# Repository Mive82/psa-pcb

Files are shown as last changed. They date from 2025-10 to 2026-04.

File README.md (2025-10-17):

# Important

**NOTE:** Unless you have access to a bunch of weird ICs used here, a way to solder 0201 and 0402 components,
and willpower to fix the defects listed below, don't bother assemblying the v1.0 version of the PCB.

# Peugeot Infotainment Project PCB

This is a repository for the PCB used in the second revision of the Peugeot Infotainment Project.
For the first revision, see the v0.1 branch.

It used <https://github.com/morcibacsi/PSAVanCanBridgeHW> as a base for the VAN communication hardware.

For more information, check out <https://github.com/Mive82/psa-docs>

## About the board

Unlike the previous v0.1 revision, on the v1.0 revision everything is contained on the board:
- Dual buck converter chips: One for the ESP and other ICs on the board (Battery power) and one for the Raspberry Pi and display (VAN+).
  - 3.3V LDO for the ESP32 after the 5V buck converter. Allows for very low voltage on the 12V input down to about 4 volts and the ESP will still work.
- ESP32-WROOM module. The USB to UART converter is not inclued, but the extra pins for resetting and flashing the board are routed to the connector.
- TSS463C VAN driver. Connected with a level shifter to the ESP
- MCP2551 CAN transciever. The RX pin is also connected to the ESP to allow receving in software.
- DS3231 RTC Chip for keeping the time. Connected to the Pi.

## Connections

The board has three JST GH connectors:
- Car power and data (JST GH 6 pin)
  - 12V battery power
  - 12V Switched (+VAN) power
  - VAN DATA and DATAB lines
- Display power output (JST GH 4 pin)
  - Outputs 5V for an external display
  - Also routes I2C pins from the Pi if needed
- ESP programming (JST GH 6 pin)
  - UART TX, RX, RTS and DTR pins as well as GND.

# Board Defects

Being the first proper revision, there are a lot of defects. Luckily they can all be solved.

## ESP flashing issues

The `GPIO12` pin is used for SPI communication with the TSS463C. It is also used as a strapping pin for determining the voltage used
to access the onboard flash. This pin is floating, so the value will not always be correct. This will result in regular booting
and flashing issues.

**SOLUTION**: Burn eFuses with `esptool.py` to permanently set the voltage used. On the ESP32-WROOM module we used, the voltage was 3.3V [Implemented]

## ESP first boot issues

When first powering the board on, the ESP will always boot into flash mode. This is because of a capacitor on the `GPIO0` pin that was not needed: `C6`.

**SOLUTION**: Remove the `C6` capacitor. [Implemented]

## VAN TX not working

The transistor switches used for putting the MCP2551 in a low-power state and resetting the TSS are not designed correctly.
They don't reset the TSS, but the MCP2551 is always put in a low power state which prevents it from sending any CAN/VAN data.

**SOLUTION**: Remove both transistor switches and surrounding hardware (`Q6`, `R21`, `R1`, `Q5` and `C1`). [Implemented]
Pull pin `Rs` on the MCP2551 to GND with a 4.7k resistor. Note that, according the datasheet, this will increase power draw
by 9 or 10 mA. [Implemented]

## ESP32 VAN RX not working after VAN+ dissapears

This issue occured due to an oversight on level shifter pins. The VCC reference pin on one side is tied to the VAN+ regulator and will
dissapear when VAN+ dissapears.

**SOLUTION**: On chip U11 cut the trace connecting pin 11 (`VCC(B)`) and `+5V ignition`. then connect pin 11 to `+5V Car Battery`. [Implemented]
Best location would the one of the pads of `R21` which is be removed to fix the issue above this one. 

### High deep sleep power consumption

The board pulls about 35mA on 12V during deep sleep. This increases the more voltage increases.
Not yet sure what is causing this, but removing the pull resistors from the `MODE` pins on the buck regulators reduces it to about 12mA.

**PARTIAL SOLUTION**: Remove `R110` and `R118`. [Implemented]

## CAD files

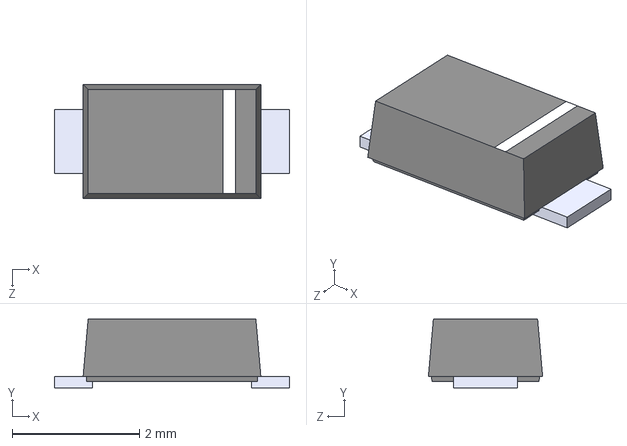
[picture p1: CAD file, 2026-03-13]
3dModels/VTVS11ASMF-M3-08.STEP
3.70 x 1.08 x 1.80 mm

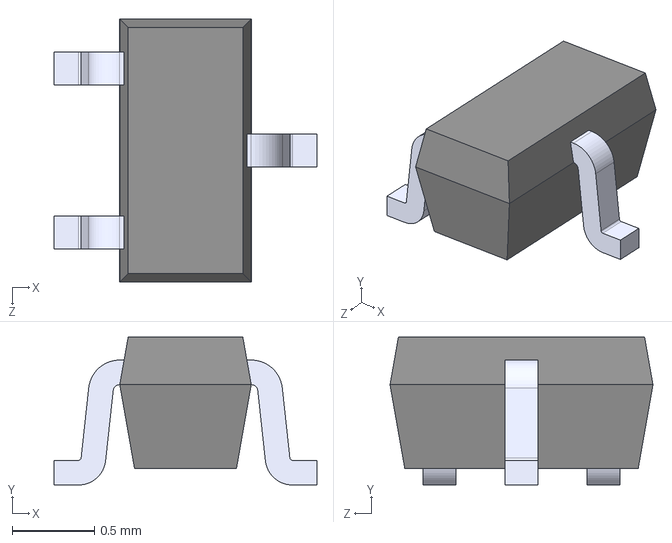
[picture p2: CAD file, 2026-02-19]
3dModels/npn.STEP
1.60 x 0.9 x 1.60 mm

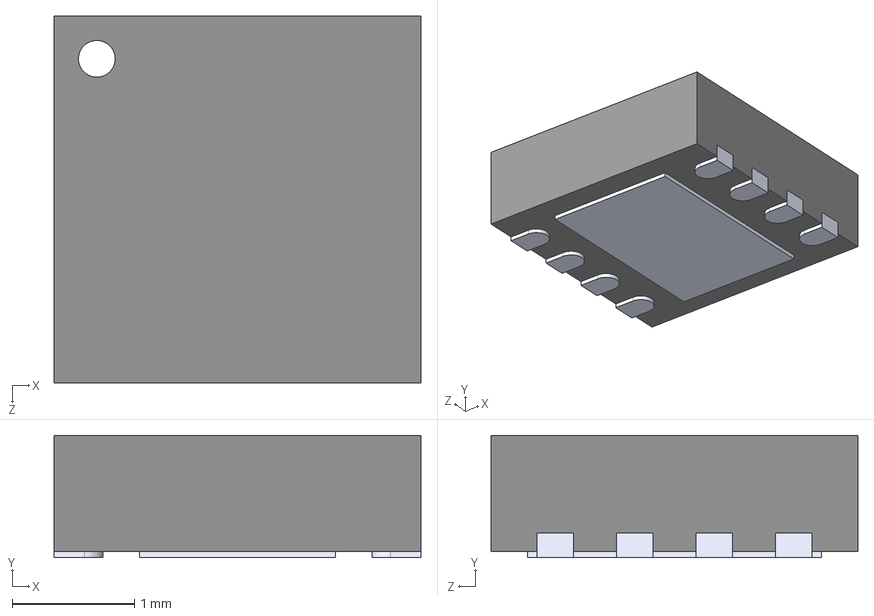
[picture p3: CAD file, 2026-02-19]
3dModels/TJA1051TK_3_1J.STEP
3.00 x 1.00 x 3.00 mm

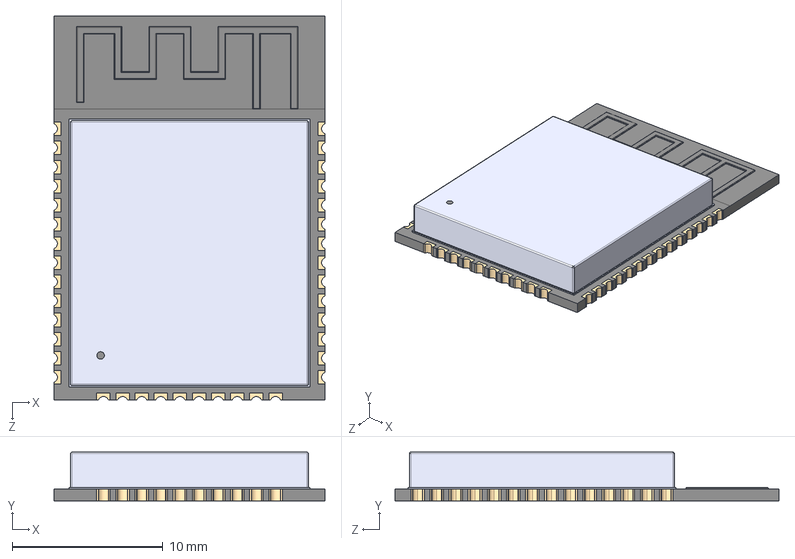
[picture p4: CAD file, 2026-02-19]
3dModels/ESP32-WROOM-32E.STEP
18.0 x 3.25 x 25.5 mm

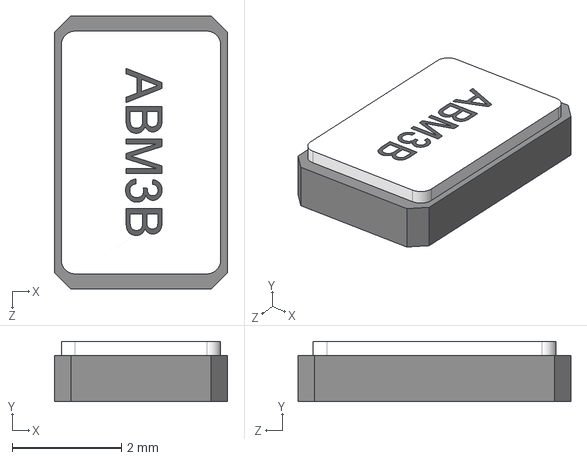
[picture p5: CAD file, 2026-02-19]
3dModels/ABM3B-8.000MHZ-B2-T--3DModel-STEP-269445.STEP
3.18 x 1.10 x 5.00 mm

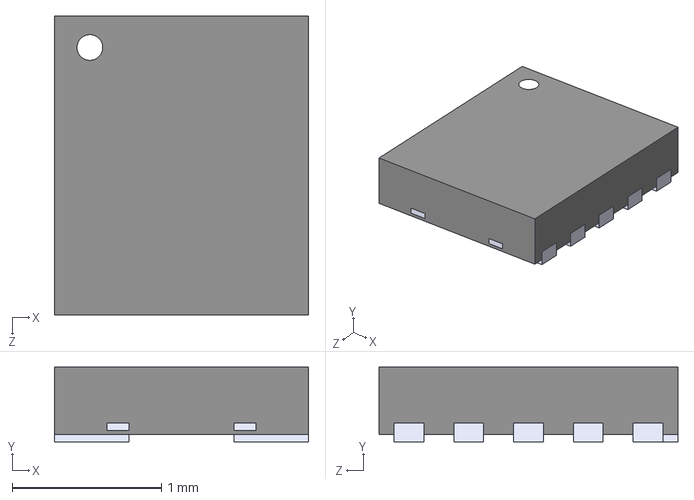
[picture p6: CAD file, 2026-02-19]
3dModels/NTS0104GU12_115.STEP
1.70 x 0.5 x 2.00 mm

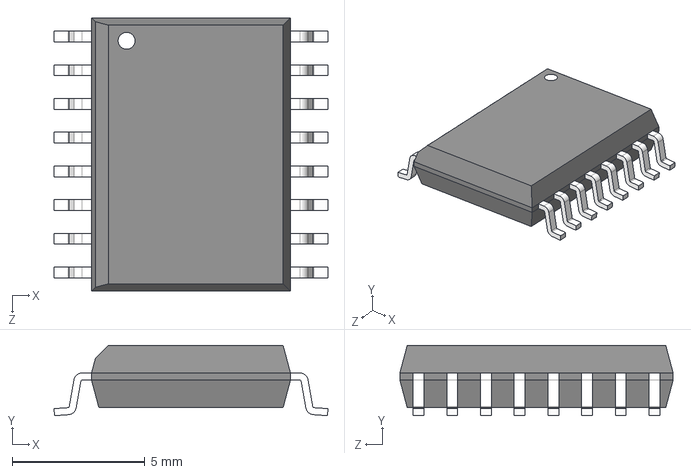
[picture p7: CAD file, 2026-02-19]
3dModels/tss463c.STEP
10.3 x 2.65 x 10.3 mm

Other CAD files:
3dModels/NCP691MN33T2G.STEP

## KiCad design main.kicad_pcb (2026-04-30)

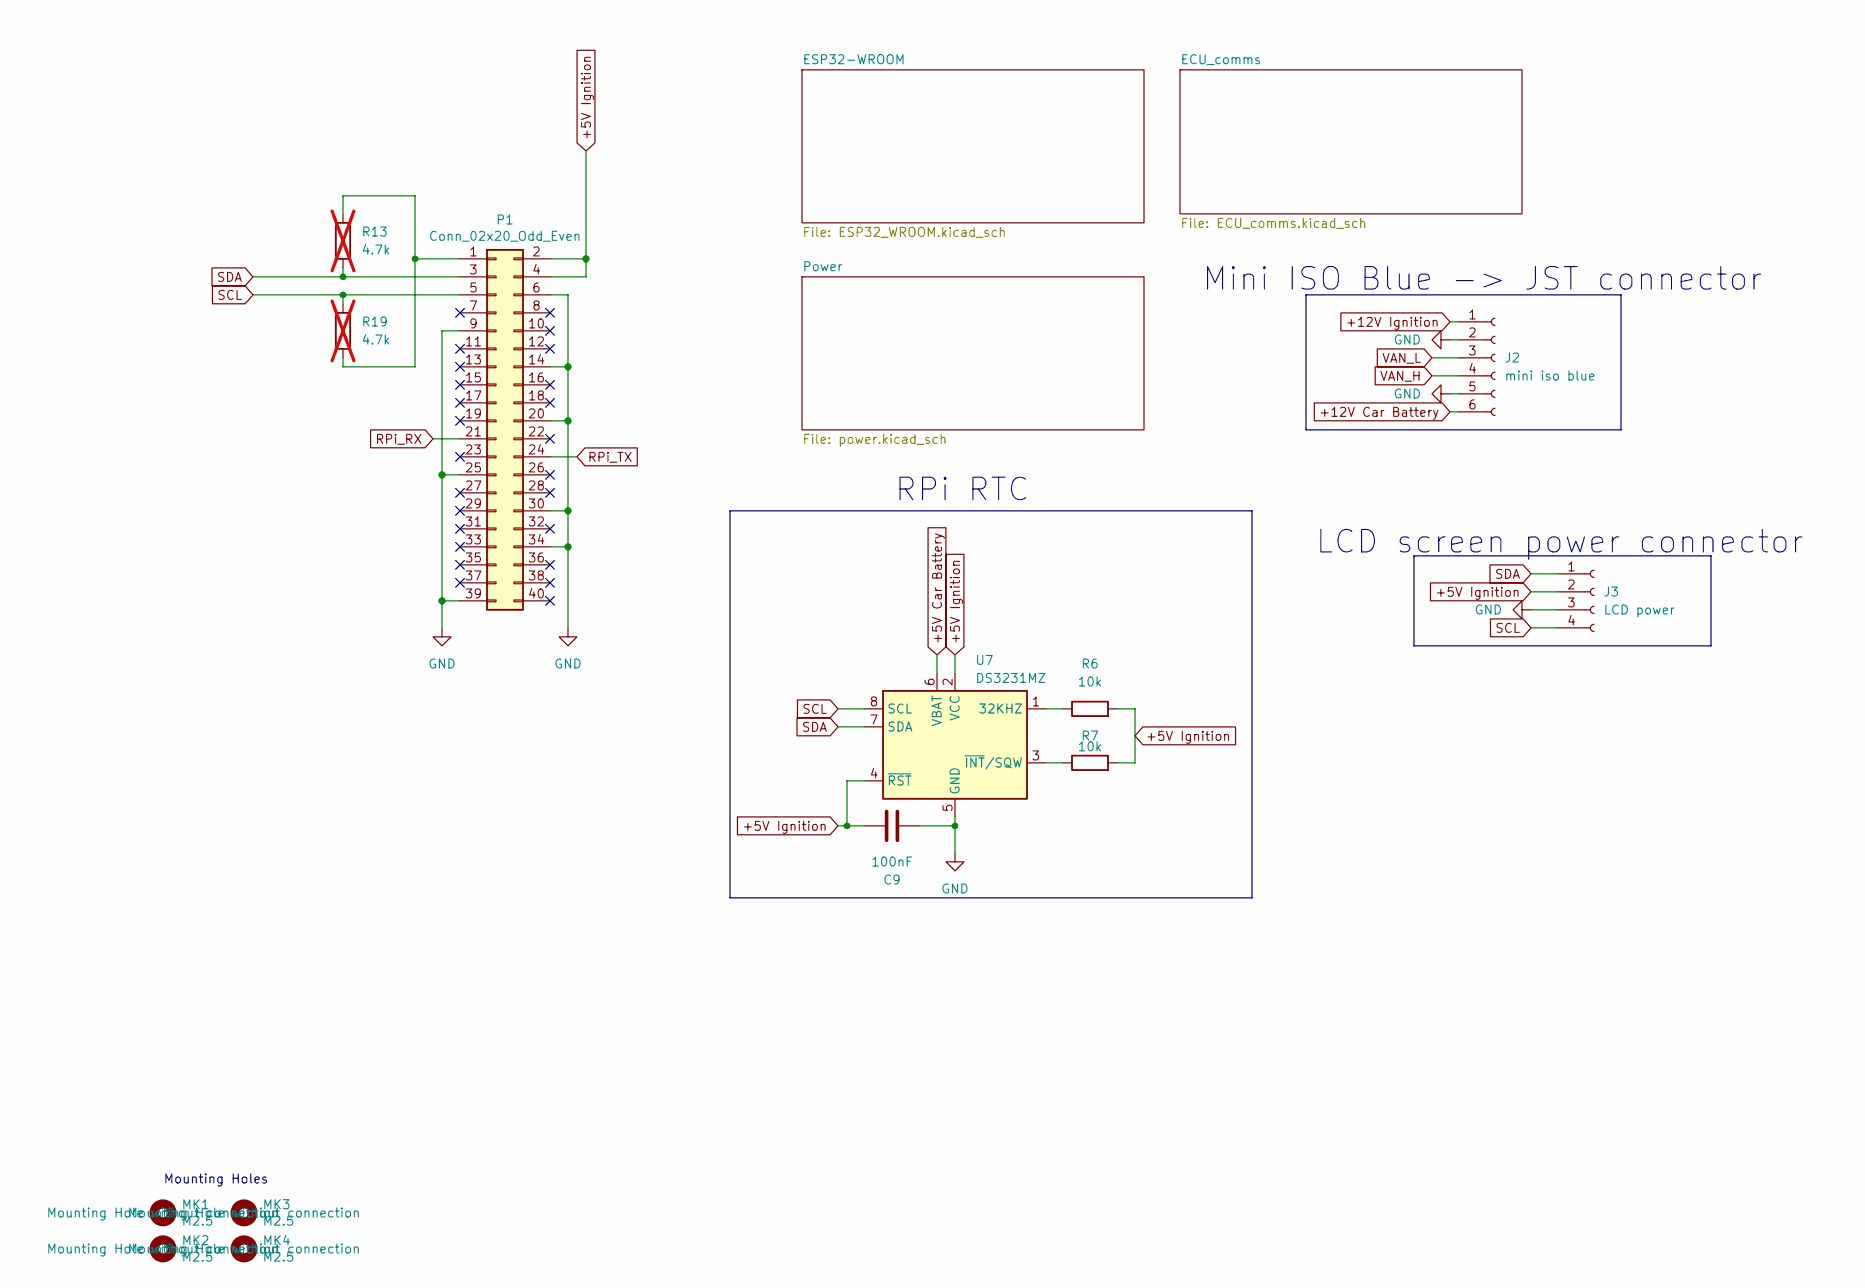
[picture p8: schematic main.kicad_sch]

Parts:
C9: 100nF; R_0805_2012Metric
J2: mini iso blue; JST_GH_SM06B-GHS-TB_1x06-1MP_P1.25mm_Horizontal
J3: LCD power; JST_GH_SM04B-GHS-TB_1x04-1MP_P1.25mm_Horizontal
MK1, MK2, MK3, MK4: M2.5; MountingHole_2.7mm_M2.5
P1: Conn_02x20_Odd_Even; PinSocket_2x20_P2.54mm_Vertical
R6, R7: 10k; R_0805_2012Metric
R13, R19: 4.7k; R_0402_1005Metric_Pad0.72x0.64mm_HandSolder; not fitted
U7: DS3231MZ; SOIC-8_3.9x4.9mm_P1.27mm

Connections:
+5V Car Battery: U7.6 (VBAT); also elsewhere on the board
+5V Ignition: C9.2, J3.2, P1.2, P1.4, R6.2, R7.2, U7.2 (VCC), U7.4 (~RST); also elsewhere on the board
+12V Car Battery: J2.6; also elsewhere on the board
+12V Ignition: J2.1; also elsewhere on the board
GND: C9.1, J2.2, J2.5, J3.3, P1.6, P1.9, P1.14, P1.20, P1.25, P1.30, P1.34, P1.39, U7.5 (GND); also elsewhere on the board
unnamed: P1.1, R13.1, R19.2
unnamed: R6.1, U7.1 (32KHZ)
unnamed: R7.1, U7.3 (~INT/SQW)
RPi_RX: P1.21; also elsewhere on the board
RPi_TX: P1.24; also elsewhere on the board
SCL: J3.4, P1.5, R19.1, U7.8 (SCL)
SDA: J3.1, P1.3, R13.2, U7.7 (SDA)
VAN_H: J2.4; also elsewhere on the board
VAN_L: J2.3; also elsewhere on the board

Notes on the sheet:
LCD screen power connector
Mini ISO Blue -> JST connector
Mounting Holes
RPi RTC

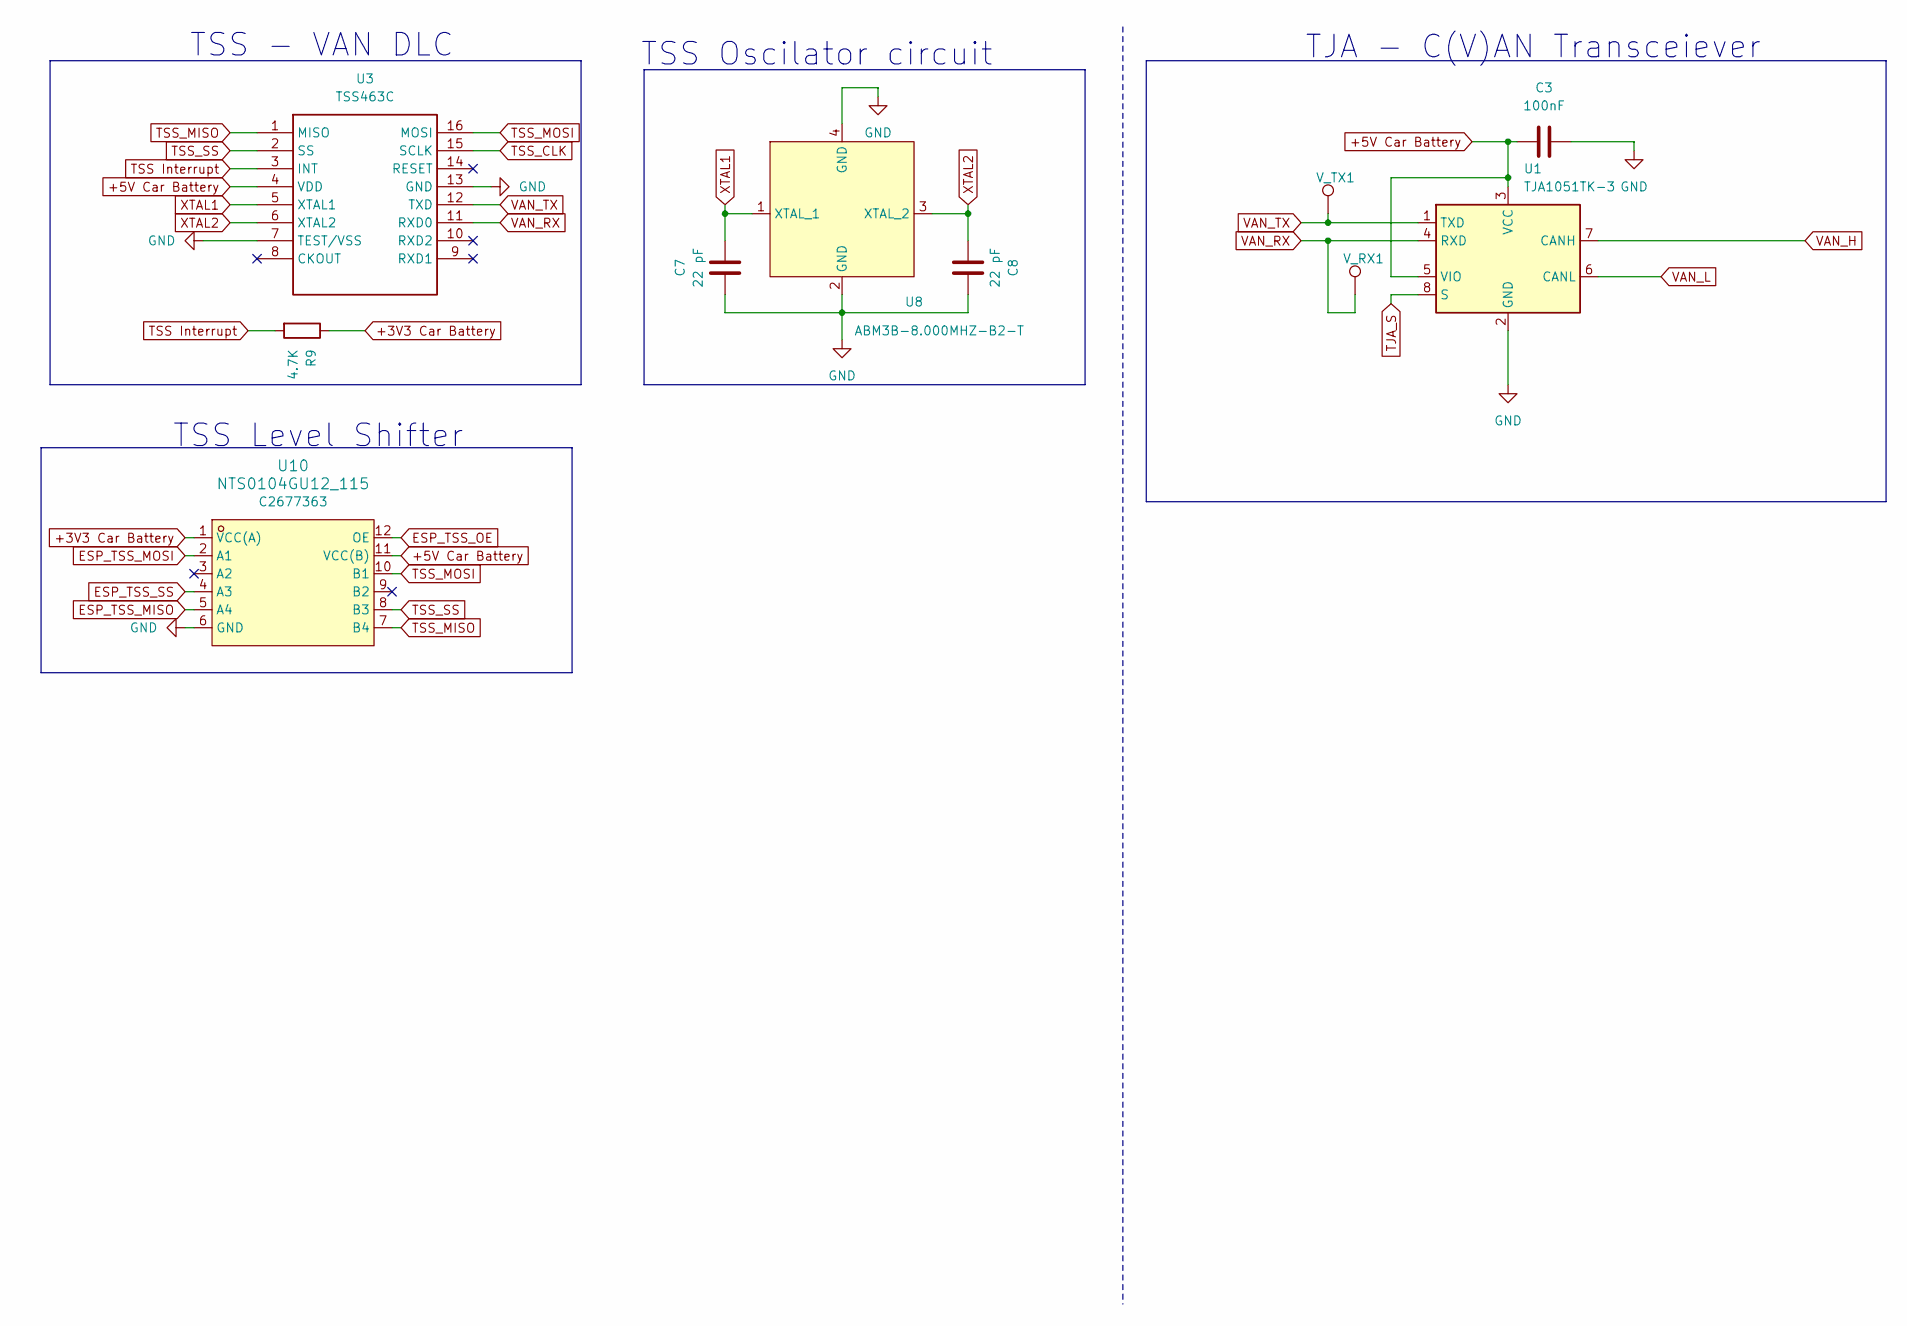
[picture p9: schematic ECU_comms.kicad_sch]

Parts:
C3: 100nF; C_0805_2012Metric
C7, C8: 22 pF; C_0805_2012Metric
R9: 4.7K; R_0805_2012Metric
U1: TJA1051TK-3; HVSON-8-1EP_3x3mm_P0.65mm_EP1.6x2.4mm
U3: TSS463C
U8: ABM3B-8.000MHZ-B2-T; Crystal_SMD_Abracon_ABM3B-4Pin_5.0x3.2mm
U10: NTS0104GU12_115; XQFN-12_L2.0-W1.7-P0.40-BL; LCSC Part C2677363
V_RX1: TestPoint; TestPoint_Pad_D1.0mm
V_TX1: TestPoint; TestPoint_Pad_D1.0mm

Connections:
+3V3 Car Battery: R9.1, U10.1 (VCC(A)); also elsewhere on the board
+5V Car Battery: C3.1, U1.3 (VCC), U1.5 (VIO), U3.4 (VDD), U10.11 (VCC(B)); also elsewhere on the board
ESP_TSS_MISO: U10.5 (A4); also elsewhere on the board
ESP_TSS_MOSI: U10.2 (A1); also elsewhere on the board
ESP_TSS_OE: U10.12 (OE); also elsewhere on the board
ESP_TSS_SS: U10.4 (A3); also elsewhere on the board
GND: C3.2, C7.1, C8.1, U1.2 (GND), U1.9 (GND), U3.7 (TEST/VSS), U3.13 (GND), U8.2 (GND), U8.4 (GND), U10.6 (GND); also elsewhere on the board
TJA_S: U1.8 (S); also elsewhere on the board
TSS Interrupt: R9.2, U3.3 (INT); also elsewhere on the board
TSS_CLK: U3.15 (SCLK); also elsewhere on the board
TSS_MISO: U3.1 (MISO), U10.7 (B4)
TSS_MOSI: U3.16 (MOSI), U10.10 (B1)
TSS_SS: U3.2 (SS), U10.8 (B3)
VAN_H: U1.7 (CANH); also elsewhere on the board
VAN_L: U1.6 (CANL); also elsewhere on the board
VAN_RX: U1.4 (RXD), U3.11 (RXD0), V_RX1.1; also elsewhere on the board
VAN_TX: U1.1 (TXD), U3.12 (TXD), V_TX1.1; also elsewhere on the board
XTAL1: C7.2, U3.5 (XTAL1), U8.1 (XTAL_1)
XTAL2: C8.2, U3.6 (XTAL2), U8.3 (XTAL_2)

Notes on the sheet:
TSS Oscilator circuit
TJA - C(V)AN Transceiever
TSS - VAN DLC
TSS Level Shifter

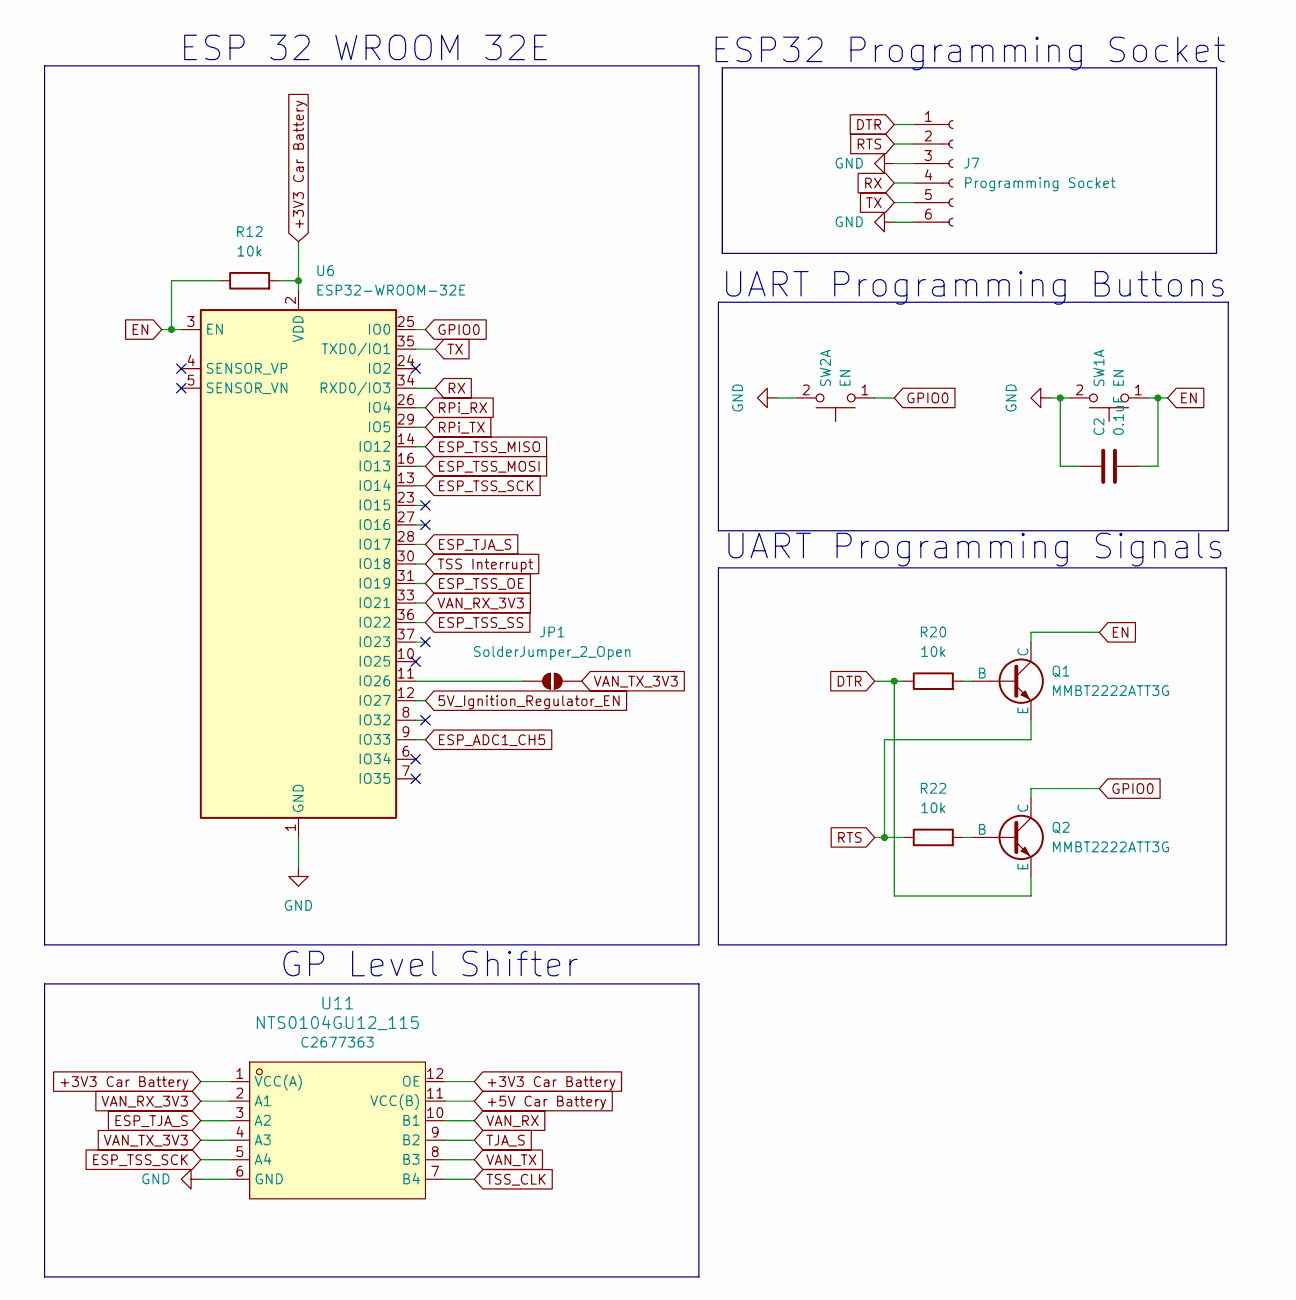
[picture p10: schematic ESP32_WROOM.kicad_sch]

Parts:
C2: 0.1uF; C_0805_2012Metric
J7: Programming Socket; JST_GH_BM06B-GHS-TBT_1x06-1MP_P1.25mm_Vertical
JP1: SolderJumper_2_Open; SolderJumper-2_P1.3mm_Open_Pad1.0x1.5mm
Q1, Q2: MMBT2222ATT3G; SOT-416
R12, R20, R22: 10k; R_0805_2012Metric
SW1, SW2: EN; SW_SPST_B3U-1000P-B
U6: ESP32-WROOM-32E; ESP32-WROOM-32D
U11: NTS0104GU12_115; XQFN-12_L2.0-W1.7-P0.40-BL; LCSC Part C2677363

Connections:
5V_Ignition_Regulator_EN: U6.12 (IO27); also elsewhere on the board
+3V3 Car Battery: R12.2, U6.2 (VDD), U11.1 (VCC(A)), U11.12 (OE); also elsewhere on the board
+5V Car Battery: U11.11 (VCC(B)); also elsewhere on the board
DTR: J7.1, Q2.3 (E), R20.1
EN: C2.2, Q1.1 (C), R12.1, SW1.1 (C), U6.3 (EN)
ESP_ADC1_CH5: U6.9 (IO33); also elsewhere on the board
ESP_TJA_S: U6.28 (IO17), U11.3 (A2)
ESP_TSS_MISO: U6.14 (IO12); also elsewhere on the board
ESP_TSS_MOSI: U6.16 (IO13); also elsewhere on the board
ESP_TSS_OE: U6.31 (IO19); also elsewhere on the board
ESP_TSS_SCK: U6.13 (IO14), U11.5 (A4)
ESP_TSS_SS: U6.36 (IO22); also elsewhere on the board
GND: C2.1, J7.3, J7.6, SW1.2 (D), SW2.2 (D), U6.1 (GND), U6.15 (GND), U6.38 (GND), U6.39 (GND), U11.6 (GND); also elsewhere on the board
GPIO0: Q2.1 (C), SW2.1 (C), U6.25 (IO0)
unnamed: JP1.1 (A), U6.11 (IO26)
unnamed: Q1.2 (B), R20.2
unnamed: Q2.2 (B), R22.2
RPi_RX: U6.26 (IO4); also elsewhere on the board
RPi_TX: U6.29 (IO5); also elsewhere on the board
RTS: J7.2, Q1.3 (E), R22.1
RX: J7.4, U6.34 (RXD0/IO3)
TJA_S: U11.9 (B2); also elsewhere on the board
TSS Interrupt: U6.30 (IO18); also elsewhere on the board
TSS_CLK: U11.7 (B4); also elsewhere on the board
TX: J7.5, U6.35 (TXD0/IO1)
VAN_RX: U11.10 (B1); also elsewhere on the board
VAN_RX_3V3: U6.33 (IO21), U11.2 (A1)
VAN_TX: U11.8 (B3); also elsewhere on the board
VAN_TX_3V3: JP1.2 (B), U11.4 (A3)

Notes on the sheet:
ESP 32 WROOM 32E
GP Level Shifter
ESP32 Programming Socket
UART Programming Signals
UART Programming Buttons

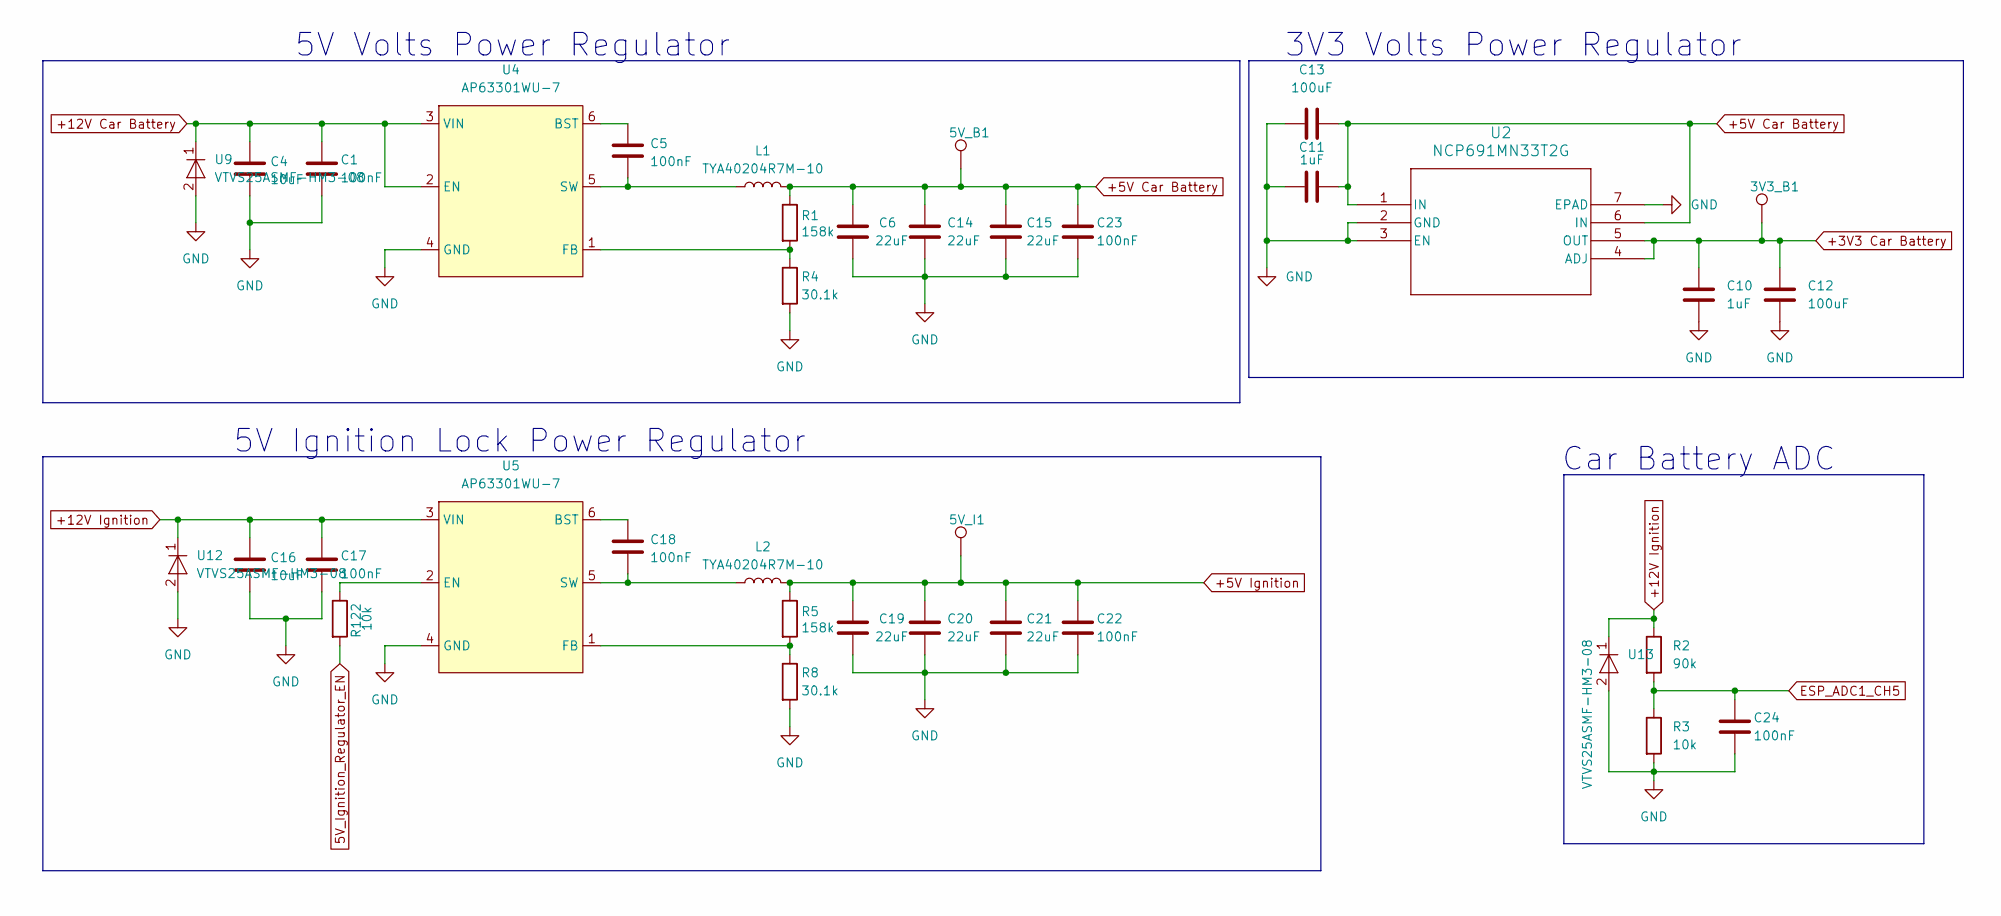
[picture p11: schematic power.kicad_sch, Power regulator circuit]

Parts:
3V3_B1, 5V_B1, 5V_I1: TestPoint; TestPoint_Pad_D1.0mm
C1, C5, C17, C18, C22, C23, C24: 100nF; C_0805_2012Metric
C4, C16: 10uF; C_0805_2012Metric
C6, C14, C15, C19, C20, C21: 22uF; C_0805_2012Metric
C10, C11: 1uF; C_0805_2012Metric
C12, C13: 100uF; C_0805_2012Metric
L1, L2: TYA40204R7M-10; IND_TYA40204_LRD
R1, R5: 158k; R_0805_2012Metric
R2: 90k; R_0805_2012Metric
R3, R122: 10k; R_0805_2012Metric
R4, R8: 30.1k; R_0805_2012Metric
U2: NCP691MN33T2G; DFN6_3X3_ONS
U4, U5: AP63301WU-7; TSOT-23-6
U9, U12, U13: VTVS25ASMF-HM3-08; D_SMF

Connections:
5V_Ignition_Regulator_EN: R122.2; also elsewhere on the board
+3V3 Car Battery: 3V3_B1.1, C10.1, C12.1, U2.4 (ADJ), U2.5 (OUT); also elsewhere on the board
+5V Car Battery: 5V_B1.1, C6.1, C11.2, C13.1, C14.1, C15.1, C23.1, L1.2, R1.1, U2.1 (IN), U2.6 (IN); also elsewhere on the board
+5V Ignition: 5V_I1.1, C19.1, C20.1, C21.1, C22.1, L2.2, R5.1; also elsewhere on the board
+12V Car Battery: C1.1, C4.1, U4.2 (EN), U4.3 (VIN), U9.1; also elsewhere on the board
+12V Ignition: C16.1, C17.1, R2.1, U5.3 (VIN), U12.1, U13.1; also elsewhere on the board
ESP_ADC1_CH5: C24.1, R2.2, R3.1; also elsewhere on the board
GND: C1.2, C4.2, C6.2, C10.2, C11.1, C12.2, C13.2, C14.2, C15.2, C16.2, C17.2, C19.2, C20.2, C21.2, C22.2, C23.2, C24.2, R3.2, R4.2, R8.2, U2.2 (GND), U2.3 (EN), U2.7 (EPAD), U4.4 (GND), U5.4 (GND), U9.2, U12.2, U13.2; also elsewhere on the board
unnamed: C5.1, U4.6 (BST)
unnamed: R1.2, R4.1, U4.1 (FB)
unnamed: C5.2, L1.1, U4.5 (SW)
unnamed: C18.1, U5.6 (BST)
unnamed: R122.1, U5.2 (EN)
unnamed: R5.2, R8.1, U5.1 (FB)
unnamed: C18.2, L2.1, U5.5 (SW)

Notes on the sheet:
5V Ignition Lock Power Regulator
Car Battery ADC
5V Volts Power Regulator
3V3 Volts Power Regulator

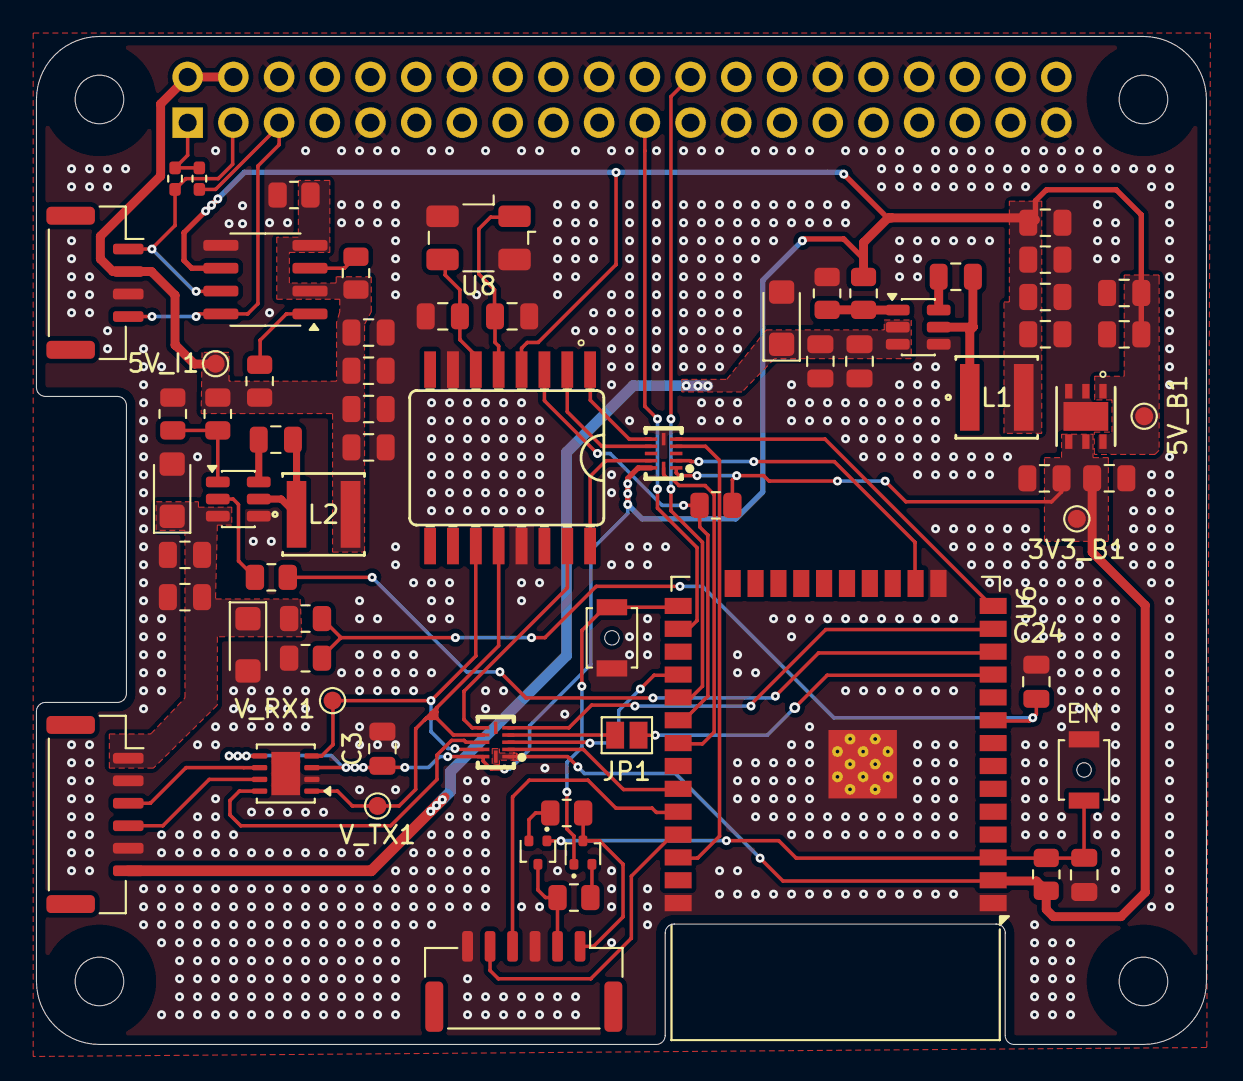
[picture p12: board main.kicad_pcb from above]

Board: 2 copper layers, 65.0 x 56.0 mm, 72 parts (1 on the bottom side), 51 nets.

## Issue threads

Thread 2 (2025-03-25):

[Research] Analyze the system parameters

Brajinovic, 2025-03-25:
As of now, I have no idea about the exact system parameters (IC parameters,  current limitations). By using the IC datasheets, I should get used to the system and get a feel for the whole project.

- [x] List the used ICs
- [x] Find their Datasheets
- [x] Identify the buck-boost converter

Used ICs:
 - ESP32 dev board - battery powered, 5V from LM7805
 - LM7805 12V -> 5V (12 V from battery)
 - MCP2551 (-I-SN) (ignition 5 V)
 - TSS463C (ignition 5 V)
 - LevelShifter 5V -> 3V3 (the 5 V are from the ignition, not from the battery).

Closed 2025-03-25.

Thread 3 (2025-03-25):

[Research] Power regulator

Brajinovic, 2025-03-25:
The LM7805 voltage regulator is a linear voltage regulator which means that the 12 to 5 V are achieved through heat dissipation. Find a switching power regulator to replace the LM7805.
  - [ ] Replacement found

Brajinovic, 2025-03-28:
In order to get rid off the noise induced with the switching power supply (buck converter), one could feed the output of the switching power supply to the input of an LDO OFC, the output of the buck should be as small as possible but at the same time enough for the LDO to work as expected.

Brajinovic, 2025-03-28:
We are going to take it from another project

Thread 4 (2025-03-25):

[Research] Low power

Brajinovic, 2025-03-25:
There are several components needing 5V, try to find out if we can replace them with 3.3 V ICs

Brajinovic, 2025-03-28:
the tSS463C is not replaceable. However, there is a possibility that we could use a 3V3 volt CAN transmitter. If my calculations are correct, the RX inputs should be able to detect a voltage level of 3.15 V as a logical HIGH. This logical HIGH detection is the bottleneck of the design.

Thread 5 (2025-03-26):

[Research] TSS463C

Brajinovic, 2025-03-26:
This chip is specific in the means that we are not going to find any suitable replacement for it so we are stuck with this IC.
- [x] VAN voltage levels
  To possibly find a replacement for the CAN transceiver (MCP 2551) I need to know the exact voltage levels that are used for the communication....

Brajinovic, 2025-03-26:
What are the VCAN voltage levels?

Vcc = 5V (from ignition contact)

Vil = -0.5 -> 0.3 * Vcc
Vih = 0.7 Vcc -> Vcc + 0.5 V

Closed 2025-03-26.

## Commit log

2022-09-16 Progress on v0.2 of the board
    [peugeot_projekt-B_Cu.gbl, peugeot_projekt-B_Mask.gbs, peugeot_projekt-B_Silkscreen.gbo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]
2022-09-16 Fix bom
2025-10-01 v1.0 - Second revision of the PCB
    [ECU_comms.kicad_sch, ESP32.kicad_sch, ESP32_WROOM.kicad_sch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]
2025-10-17 implemented the changes from 'Board defects'
    [ECU_comms.kicad_sch, ESP32_WROOM.kicad_sch, main.kicad_sch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]
2025-11-03 2 layer PCB
    [ECU_comms.kicad_sch, ESP32_WROOM.kicad_sch, main.kicad_pcb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]
2026-02-14 changed the CAN transceiever; fixed the transiever typo
    [ECU_comms.kicad_sch, ESP32_WROOM.kicad_sch, main.kicad_pcb]
2026-02-17 added direct VAN_TX to ESP connection
    [ESP32_WROOM.kicad_sch, main.kicad_pcb, power.kicad_sch]
2026-02-18 changed power regulators, updated PCB
    [ECU_comms.kicad_sch, ESP32_WROOM.kicad_sch, main.kicad_pcb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]
2026-02-19 added 3D models; light touch-ups
    [ABM3B-8.000MHZ-B2-T--3DModel-STEP-269445.STEP, ECU_comms.kicad_sch, ESP32-WROOM-32E.STEP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]
2026-02-19 removed temp file OUTPUT
    [main-B_Cu.gbr, main-B_Mask.gbr, main-B_Paste.gbr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]
2026-02-20 switched to vertial program connector, changed logo position
    [ESP32_WROOM.kicad_sch, main.kicad_pcb]
2026-03-13 added tvs diodes, 100nF, pull-up for TSS interrupt
    [ECU_comms.kicad_sch, ESP32_WROOM.kicad_sch, VTVS11ASMF-M3-08.STEP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]
2026-03-15 Modified ADC resistors. Added bypass cap to ADC.
    Removed some ground islands.
    Removed lock files and added them to gitignore.
    [ECU_comms.kicad_sch, main.kicad_pcb, power.kicad_sch]
2026-04-30 Change inductor type.
    [ECU_comms.kicad_sch, ESP32_WROOM.kicad_sch, main.kicad_pcb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]
2026-04-30 Update bom values with actual chip names
    [ECU_comms.kicad_sch, ESP32_WROOM.kicad_sch, main.kicad_pcb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]
